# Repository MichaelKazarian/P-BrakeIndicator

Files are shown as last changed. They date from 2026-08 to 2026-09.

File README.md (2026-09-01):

# P-BrakeIndicator

**P-BrakeIndicator:** An ATtiny202-based automotive buzzer alert system to prevent driving with the handbrake engaged.

Компактний автомобільний пристрій контролю стоянкового гальма на мікроконтролері **ATtiny202** (серія tinyAVR 0). Система моніторить положення важеля ручника та активує звукове сповіщення у разі спроби руху з піднятим ручним гальмом, запобігаючи передчасному зносу гальмівної системи автомобіля.

---

## 🛠️ Апаратне забезпечення та інструменти

* **Мікроконтролер:** ATtiny202 (в корпусі SOIC-8).
* **Програматор:** USB-UART (TTL) адаптер на базі чіпа **QinHeng Electronics HL-340**.
* **Додатково:** Резистор **4.7 кОм** (або діод на кшталт 1N4148 / червоний світлодіод) для створення лінії SerialUPDI.

---

## 📊 Розпіновка та Специфікація (Pinout & Specification)

Для зручності монтажу та проектування нижче наведено схему розташування виводів мікроконтролера ATtiny202 (корпус SOIC-8) та його основні технічні характеристики:

<p align="center">
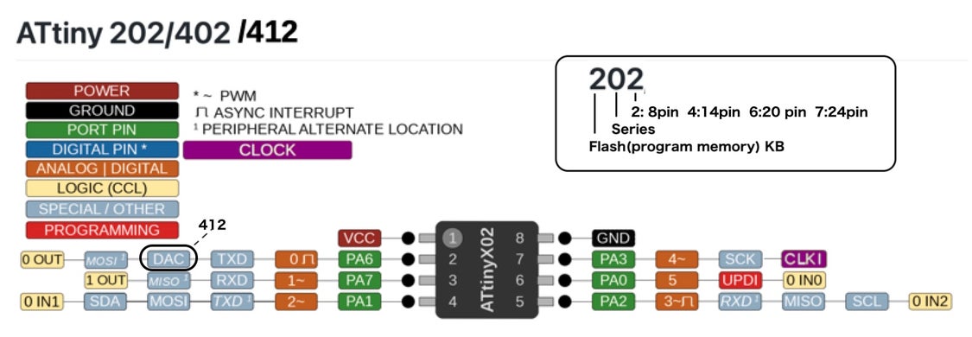
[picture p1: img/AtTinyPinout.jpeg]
ATtiny202 Pinout Map
  
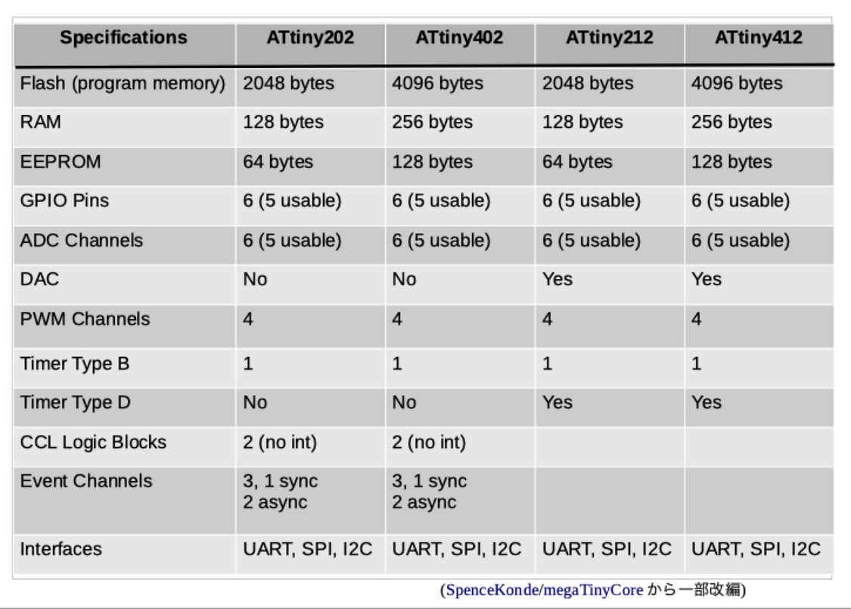
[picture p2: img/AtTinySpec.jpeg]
ATtiny202 Specification
  
</p>

---

## 🔌 Схема підключення (SerialUPDI)

Оскільки інтерфейс UPDI є однопровідним, лінії TX та RX адаптера HL-340 об'єднуються через резистор:

```text
USB-UART HL-340                       ATtiny202 (SOIC-8)
   [ TX ] -----[ Резистор 4.7 кОм ]-----+
                                        |
   [ RX ] ------------------------------+------> Pin 6 (PA0 / UPDI)

   [ GND ] ------------------------------------> Pin 8 (GND)
   [ 3.3V ] -----------------------------------> Pin 1 (VCC)
```
Для кращого розуміння фізичного монтажу ліній зв'язку нижче наведено візуальну схему:

<p align="center">
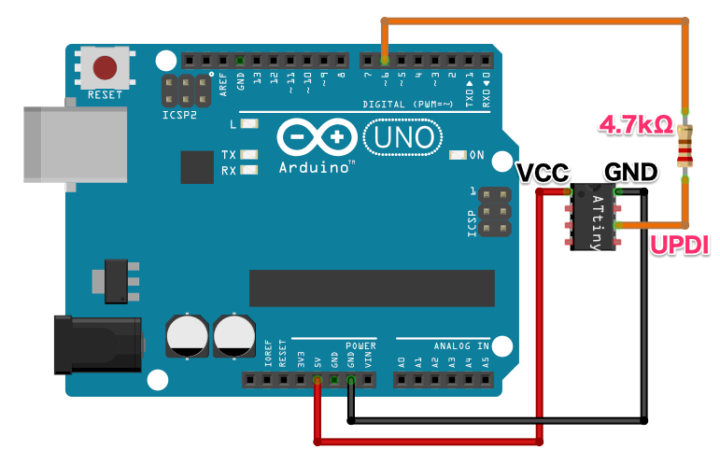
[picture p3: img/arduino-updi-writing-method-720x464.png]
UPDI Connection Diagram
  
</p>

⚠️ На цьому зображенні як апаратний міст показано плату Arduino. Проте **принцип об'єднання сигнальних ліній через резистор та підключення до чіпа повністю аналогічні нашому програматору** на базі USB-UART HL-340. Лінії передачі даних працюють за тією ж напівдуплексною логікою.

⚠️ **Важлива особливість для HL-340:** Адаптер видає логічні рівні 3.3 В. Для стабільної ініціалізації чіпа (щоб уникнути помилки `UPDI initialisation failed`), мікроконтролер ATtiny202 обов'язково має бути заживлений від **3.3 В**, а не від 5 В.

---

## 💻 Розробка за допомогою PlatformIO (Рекомендовано)

Для автоматизації збірки, керування життєвим циклом проєкту та комфортної роботи в текстових редакторах (наприклад, **Emacs**) використовується **PlatformIO Core**. 

Застарілий метод прошивки через `jtag2updi` більше **не працює**, тому конфігурація налаштована на пряме програмування через інтерфейс **SerialUPDI**.

### 1. Конфігурація `platformio.ini`
Рекомендованим способом ініціалізувати проект є виклик

``` shell
make init
```

або вручну

``` shell
platformio project init --ide emacs --board ATtiny202 \
--project-option "framework=arduino" \
--project-option "board_build.f_cpu=16000000L" \
--project-option "upload_protocol=serialupdi" \
--project-option "upload_speed=57600" \
# --project-option "upload_port=/dev/ttyUSB0"
# Автоматичне визначення або ручний вибір порту (за потреби розкоментуйте рядок вище)
```

Цей виклик згенерує структуру проекту і файл налаштувань `platformio.ini`. Додайте в кінець ці рядки:

``` ini
; Automatic detection or manual port selection (uncomment if needed)
; upload_port = /dev/ttyUSB0

[env:brake_indicator]
extends = env:ATtiny202
src_filter = +<brake_indicator.c> -<blink_test.c>

[env:blink_test]
extends = env:ATtiny202
src_filter = +<blink_test.c> -<brake_indicator.c>
```

Після ініціалізації проєкту файл налаштувань має містити параметри частоти, фіксованого порту та зниженої швидкості завантаження (`57600`), яка є критичною для стабільної роботи старого китайського чіпа HL-340 та профілі прошивки `brake_indicator` та `blink_test`:

```ini
[env:attiny202]
platform = atmelmegaavr
board = attiny202
framework = arduino
board_build.f_cpu = 16000000L
upload_protocol = serialupdi
upload_speed = 57600

; Automatic detection or manual port selection (uncomment if needed)
; upload_port = /dev/ttyUSB0

[env:brake_indicator]
extends = env:ATtiny202
src_filter = +<brake_indicator.c> -<blink_test.c>

[env:blink_test]
extends = env:ATtiny202
src_filter = +<blink_test.c> -<brake_indicator.c>
```

### 2. Керування проєктом через Makefile
Для швидкої збірки та прошивки безпосередньо з робочого оточення використовується дворівнева структура `Makefile`. Головний файл у корені проєкту автоматизує основні команди:

* `make init` — ініціалізує чистий проєкт для архітектури ATtiny202 з усіма необхідними параметрами прошивки та створює конфігурацію для Emacs.
* `make build` — компілює основний код програми (`brake_indicator.c`).
* `make upload` — прошиває мікроконтролер через підключений адаптер HL-340.
* `make upload-blink` — прошиває тестовий код блінка (`blink_test.c`) для перевірки заліза.
* `make clean` — очищає тимчасові файли збірки.
* `make monitor` — запускає монітор послідовного порту.

Внутрішній `src/Makefile` автоматично перенаправляє виклики на рівень вище за допомогою прапорця `-C ..`, що дозволяє запускати компіляцію чи прошивку прямо під час редагування файлу `src/main.cpp`.

## ⚙️  Альтернативне налаштування в Arduino IDE

1. Встановіть ядро **megaTinyCore** від SpenceKonde, додавши це посилання в менеджер плат:
   `https://github.com/SpenceKonde/megaTinyCore`
2. Перейдіть в **Інструменти** (Tools) та виберіть такі налаштування:
   * **Плата (Board):** megaTinyCore ➔ ATtiny202/402/212/412 (БЕЗ Optiboot!) *(Окремого пункту Bootloader немає, вибір інтегровано сюди)*
   * **Chip:** ATtiny202
   * **Clock:** 16 MHz internal
   * **Programmer:** `SerialUPDI - 57600 baud` *(Швидкість 57600 є критичною для стабільної роботи старого чіпа HL-340)*
   * **Port:** Ваш COM-порт (наприклад, `/dev/ttyUSB0` у Linux)

---

## 🚀 Як завантажити код

1. Підключіть тестовий світлодіод довгою ніжкою до **ніжки 2 (PA6)**, а короткою через резистор 220 Ом до **GND**.
2. Перевірте, що в меню вибору плат активовано саме варіант **(БЕЗ Optiboot!)**.
3. Натисніть стандартну кнопку **«Вантажити» (Upload)** в Arduino IDE. Програма автоматично викличе SerialUPDI та завантажить скетч.

---

## 📝 Тестовий скетч

У коді для PlatformIO обов'язково підключається заголовок `<Arduino.h>`, а піни задаються через системні константи. Для цього тесту світлодіод підключається до порту **PA3**, що фізично відповідає **ніжці 7** мікроконтролера ATtiny202.

Схема підключення світлодіода для перевірки працездатності:

<p align="center">
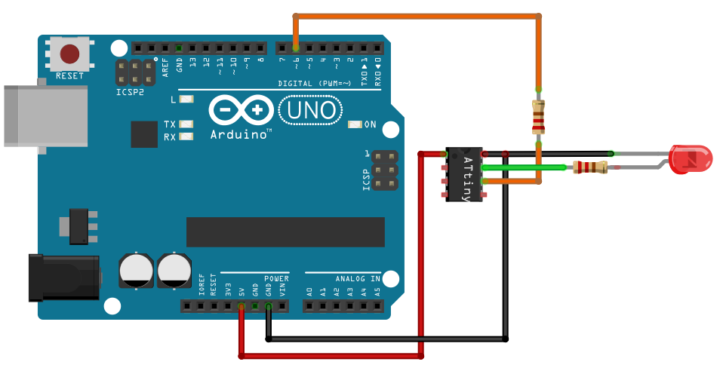
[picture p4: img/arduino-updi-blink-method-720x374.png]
ATtiny202 LED Connection Diagram
  
</p>

### Код програми (`src/blink_test.c`)

```c
#include <Arduino.h>

// Для ATtiny202 в PlatformIO піни позначаються через PIN_PA6, PIN_PA7 тощо.
// Фізична ніжка 7 чіпа — це порт PA3.
const uint8_t LED_PIN = PIN_PA3; 

void setup() {
  pinMode(LED_PIN, OUTPUT);
}

void loop() {
  digitalWrite(LED_PIN, HIGH);
  delay(1000);
  digitalWrite(LED_PIN, LOW);
  delay(1000);
}
```

### Результат роботи

Після успішного завантаження програми світлодіод почне блимати з інтервалом в одну секунду, як показано на зображенні:

<p align="center">
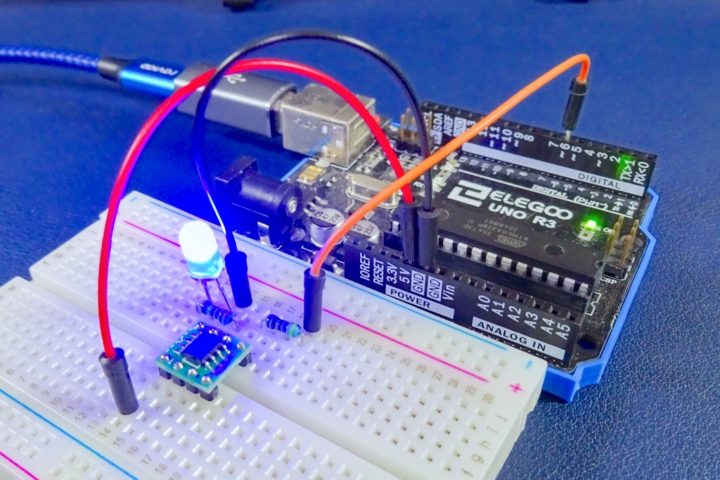
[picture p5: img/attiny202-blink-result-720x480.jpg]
ATtiny202 Blink Result
  
</p>

---

## 🔊 Схема підключення звукового випромінювача (2Т7000 MOSFET)

Для відтворення мелодії пасивний динамік або зумер підключається через N-канальний польовий транзистор **2N7000** за схемою Low-Side Switch. Для стабільної роботи без просідання живлення та захисту від перезавантаження мікроконтролера обов'язково використовуються обмежувальний, затворний та підтягуючий резистори:

* **Source (Витік / Ніжка 1 транзистора):** Підключається жорстко на **GND (Мінус / Маса)**.
* **Drain (Стік / Ніжка 3 транзистора):** Підключається до мінусового виводу динаміка.
* **Резистор 10 Ом (Gate Resistor):** Встановлюється у розрив лінії між виводом **PA3** та Затвором (Gate) для гасіння високочастотного дзвону та обмеження зарядного струму затвора.
* **Резистор 1 кОм (Pull-Down):** Встановлюється між Затвором (Gate) та Витоком (Source) для надійного закриття транзистора, коли мікроконтролер мовчить.
* **Резистор 100 Ом (Струмообмежувальний):** Підключається послідовно з динаміком у розрив ланцюга живлення **VCC (+3.3V / +5V)** для захисту лінії від імпульсних просідань напруги.

---

## 🔗 Корисні посилання
* [Посилання на специфікацію ATtiny202](https://ameblo.jp/pta55/entry-12784013578.html)
*Зверніть увагу: застарілий метод прошивки через `jtag2updi` більше **не працює** з новими версіями ядер, тому використовується пряме програмування через SerialUPDI.*
* [Детальна інструкція з налаштування середовища розробки ATtiny202 в Arduino IDE](https://burariweb.info)

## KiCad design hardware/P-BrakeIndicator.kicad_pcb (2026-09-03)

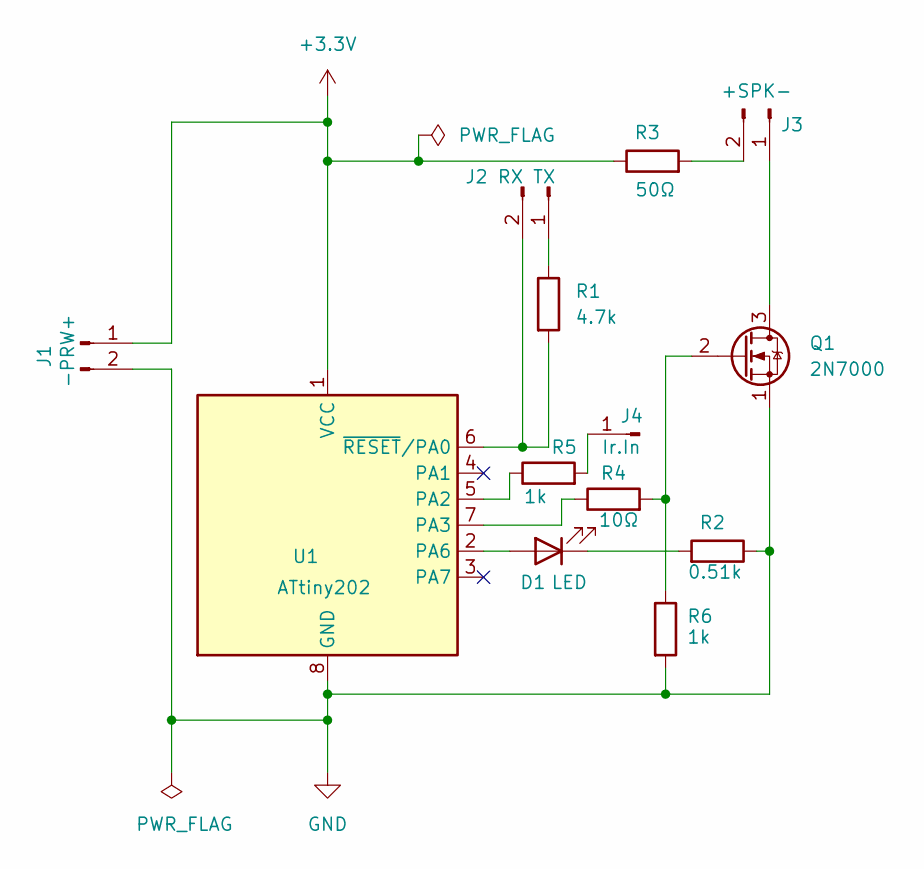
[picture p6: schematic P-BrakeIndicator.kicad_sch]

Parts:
D1: LED; LED_D5.0mm
J1: -PRW+; PinHeader_1x02_P2.54mm_Vertical
J2: RX TX; PinHeader_1x02_P2.54mm_Vertical
J3: +SPK-; PinHeader_1x02_P2.54mm_Vertical
J4: Ir.In; PinHeader_1x01_P2.54mm_Vertical
Q1: 2N7000; TO-92_Inline
R1: 4.7k; R_Axial_DIN0207_L6.3mm_D2.5mm_P7.62mm_Horizontal
R2: 0.51k; R_Axial_DIN0207_L6.3mm_D2.5mm_P7.62mm_Horizontal
R3: 50Ω; R_Axial_DIN0207_L6.3mm_D2.5mm_P7.62mm_Horizontal
R4: 10Ω; R_Axial_DIN0207_L6.3mm_D2.5mm_P7.62mm_Horizontal
R5, R6: 1k; R_Axial_DIN0207_L6.3mm_D2.5mm_P7.62mm_Horizontal
U1: ATtiny202; DIP-8_W7.62mm

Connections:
+3.3V: J1.1, R3.1, U1.1 (VCC)
GND: J1.2, Q1.1 (S), R2.1, R6.2, U1.8 (GND)
unnamed: D1.2 (A), U1.2 (PA6)
unnamed: D1.1 (K), R2.2
unnamed: J2.1, R1.1
unnamed: J2.2, R1.2, U1.6 (~RESET/PA0)
unnamed: J3.1, Q1.3 (D)
unnamed: J3.2, R3.2
unnamed: J4.1 (Pin_1_1), R5.2
unnamed: Q1.2 (G), R4.2, R6.1
unnamed: R5.1, U1.5 (PA2)
unnamed: R4.1, U1.7 (PA3)

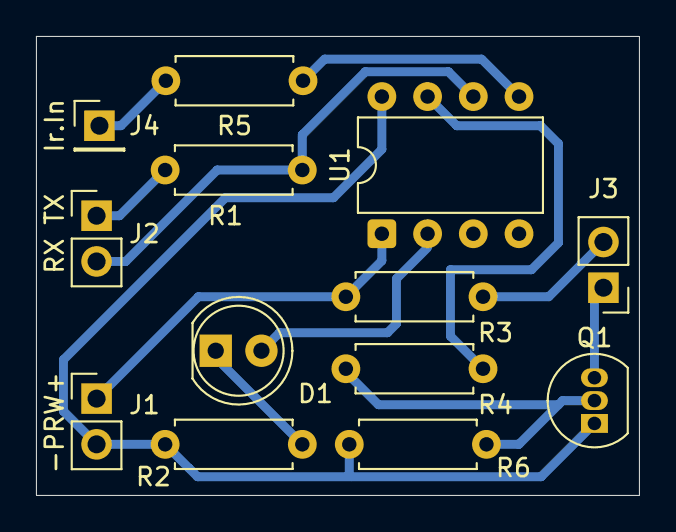
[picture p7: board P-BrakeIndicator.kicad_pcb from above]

Board: 2 copper layers, 33.5 x 25.5 mm, 13 parts (0 on the bottom side), 12 nets.

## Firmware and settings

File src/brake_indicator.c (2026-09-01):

#include <Arduino.h>
#include "brake_indicator.h"

unsigned long handbrakeTimer = 0;
bool isBraking = false;

void setup(void) {
  pinMode(SENSOR_DIGITAL, INPUT_PULLUP);
  pinMode(SPEAKER_PIN, OUTPUT);
  pinMode(LED_PIN, OUTPUT);
}

void playTone(uint16_t halfPeriodUs, uint16_t durationMs) {
  uint32_t cyclesTotalUs = (uint32_t)durationMs * 1000UL;
  uint32_t elapsedUs = 0;

  digitalWrite(LED_PIN, HIGH);
  while (elapsedUs < cyclesTotalUs) {
    digitalWrite(SPEAKER_PIN, HIGH);
    delayMicroseconds(halfPeriodUs);
    digitalWrite(SPEAKER_PIN, LOW);
    delayMicroseconds(halfPeriodUs);
    elapsedUs += (uint32_t)halfPeriodUs * 2;
  }
  digitalWrite(LED_PIN, LOW);
}

void playWarningMelody(void) {
  playTone(NOTE_E6_HALF_PERIOD, NOTE_DURATION); delay(NOTE_PAUSE); // E6 (Мі6)
  playTone(NOTE_G6_HALF_PERIOD, NOTE_DURATION); delay(NOTE_PAUSE); // G6 (Соль6)
  playTone(NOTE_B6_HALF_PERIOD, NOTE_DURATION); // B6 (Сі6)
}

void loop(void) {
  bool handbrakeActive = (digitalRead(SENSOR_DIGITAL) == HIGH);

  if (handbrakeActive) {
    digitalWrite(LED_PIN, HIGH);
    if (!isBraking) {
      handbrakeTimer = millis(); 
      isBraking = true;
    }
    if (millis() - handbrakeTimer > DELAY_BEFORE_START) {
      playWarningMelody();
      delay(DELAY_BETWEEN_ALER_CYCLES); 
    }
  } else {
    isBraking = false;
    digitalWrite(SPEAKER_PIN, LOW);
    digitalWrite(LED_PIN, LOW);
  }
}

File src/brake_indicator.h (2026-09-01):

#ifndef BRAKE_INDICATOR_H
#define BRAKE_INDICATOR_H

#include <Arduino.h>

// --- Pin configuration for ATtiny202 ---
#define SENSOR_DIGITAL PIN_PA2
#define SENSOR_ANALOG  PIN_PA1
#define SPEAKER_PIN    PIN_PA3
#define LED_PIN        PIN_PA6

// --- Timing and algorithm settings ---
#define DELAY_BEFORE_START 700 
#define DELAY_BETWEEN_ALER_CYCLES 1200
#define NOTE_DURATION 150
#define NOTE_PAUSE 50

// --- Note periods in microseconds (1000000 / Hz) ---
#define NOTE_E6_HALF_PERIOD 379  // 1318 Hz -> full period 758 us
#define NOTE_G6_HALF_PERIOD 319  // 1567 Hz -> full period 638 us
#define NOTE_B6_HALF_PERIOD 253  // 1975 Hz -> full period 506 us

void playWarningMelody(void);
void playTone(uint16_t halfPeriodUs, uint16_t durationMs);

#endif // BRAKE_INDICATOR_H

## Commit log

2026-08-26 doc: embed wiring diagram image into SerialUPDI section
2026-08-26 feat: implement P-BrakeIndicator core logic in brake_indicator.c
2026-08-26 refactor: improve tone generation logic and export prototypes to header
2026-08-26 doc: document 2N7000 MOSFET driver configuration in README
2026-09-01 fix: swap sensor pins and invert handbrake logic to active-high
    [brake_indicator.c, brake_indicator.h]
2026-09-01 doc: correction of 2N7000 resistor values in README schematic descriptor
2026-09-01 pcb: Add PCB layout and ignore KiCad history
    [P-BrakeIndicator.kicad_pcb, P-BrakeIndicator.kicad_sch]
2026-09-01 pcb: widen power traces and relocate hardware project assets
    [P-BrakeIndicator.kicad_pcb, P-BrakeIndicator.kicad_sch]
2026-09-03 pcb: update component values and increase track widths to 0.5mm
    [P-BrakeIndicator.kicad_pcb, P-BrakeIndicator.kicad_sch]
